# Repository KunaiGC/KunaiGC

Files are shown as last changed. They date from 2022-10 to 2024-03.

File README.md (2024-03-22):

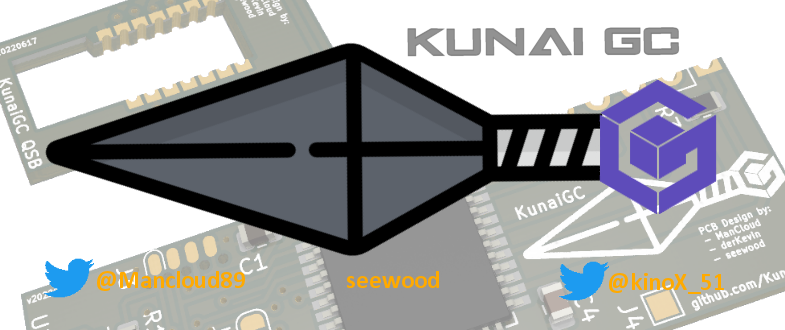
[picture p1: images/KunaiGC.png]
KunaiGC WIP


# KunaiGC
It is a OpenSource IPL modchip for the Nintendo Gamecube which provides a rich featureset. 
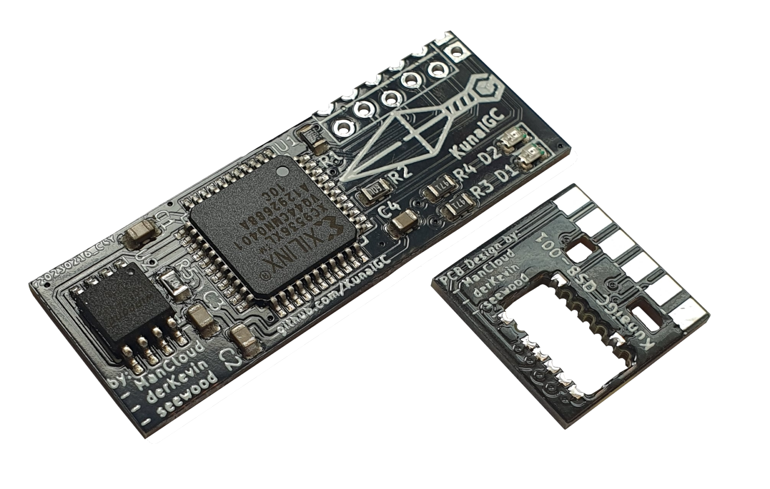
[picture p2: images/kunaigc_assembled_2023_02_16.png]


## Features
* QSB - Quick Solder Board for easy installation process
* Flash storage - boot directly into internal Swiss or GBI (Game Boy Interface)
* configurable boot-behavior
* Button mapped .dol file loading 
* Boot discs from all regions via build-in swiss
* KunaiUpdater - Update/Install Firmware, internal Swiss and GBI (Game Boy Interface) via SD-Card
* KunaiRecovery
* Cubeboot support

## Guides and Wiki

* just take a look at MachoNachos video:
[The Gamecube Just Got A NEW Modchip | The kunaiGC](https://www.youtube.com/watch?v=YmsjPn3J_iU)
* visit our [**Wiki-Page**](https://github.com/KunaiGC/KunaiGC/wiki) for detailed informations

## Installation

* The QSB is pretty straight forward and you only need to solder a few given spots. Make sure to check [**the solder guide**](https://github.com/KunaiGC/KunaiGC/wiki/Installation)

## Update the KunaiGC
* To update the KunaiGC firmware, the internal swiss version or install gbi (Game Boy Interface) please follow the [update instructions](https://github.com/KunaiGC/KunaiGC/wiki/Update-the-KunaiGC)

## You want to support our development?

head over to your favorite shop and order your own KunaiGC
* [Swiss] consoles4you: https://consoles4you.ch/en/kunaigc-mod-chip
* [US] stoneagegamer: https://stoneagegamer.com/kunaigc.html
* [France] mod in france: https://shop.modinfrance.fr/en/gamecube/60-kunaigc-for-gamecube.html
* [UK] retro upgrades: https://www.retroupgrades.co.uk/product/kunaigc-modchip/

## Credits
* #gc-forever crew: [Extrems](https://github.com/Extrems), [emu_kidid](https://github.com/emukidid) for doing the best job on swiss and homebrew, [novenary](https://github.com/9ary) especially for gaving us the permission to make his [gc-ipl](https://github.com/redolution/gc-ipl) great again 
* [tmbinc](https://github.com/tmbinc) - making ipl modchips possible
* happy_bunny and [webhdx](https://github.com/webhdx) for their research on the [shuriken attack](https://www.retro-system.com/shuriken_attack.htm) and [PicoBoot](https://github.com/webhdx/PicoBoot)
* KunaiGC beta testers from [CiBo](https://circuit-board.de/forum/), [psxtools.de](psxtools.de) and [EnterpriseFreak](https://github.com/EnterpriseFreak-v2)
* The handsome guys :p [Voultar](https://voultar.com/) and [MachoNacho](https://www.youtube.com/c/MachoNachoProductions)
* everyone who supports us 

## Licence 
 * The Hardware was developed under CC BY-NC-SA (Creative Commons Attribution-NonCommercial-ShareAlike 4.0 International)
 * The Software was developed under GNU GPL 2 (GNU GENERAL PUBLIC LICENSE 2)

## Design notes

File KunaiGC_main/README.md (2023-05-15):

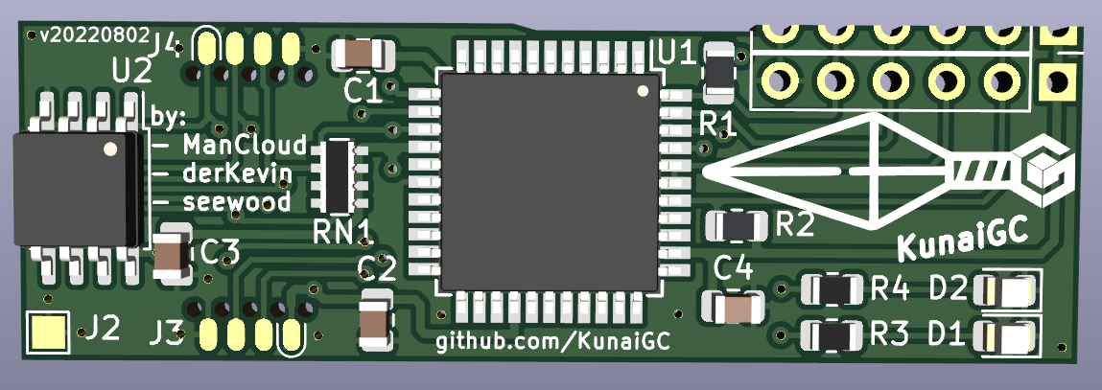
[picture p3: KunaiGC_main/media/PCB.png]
KunaiGC main PCB


# KunaiGC main PCB
The actual Modchip.

for its BOM please see [the Wiki](https://github.com/KunaiGC/KunaiGC/wiki/Build-the-KunaiGC)

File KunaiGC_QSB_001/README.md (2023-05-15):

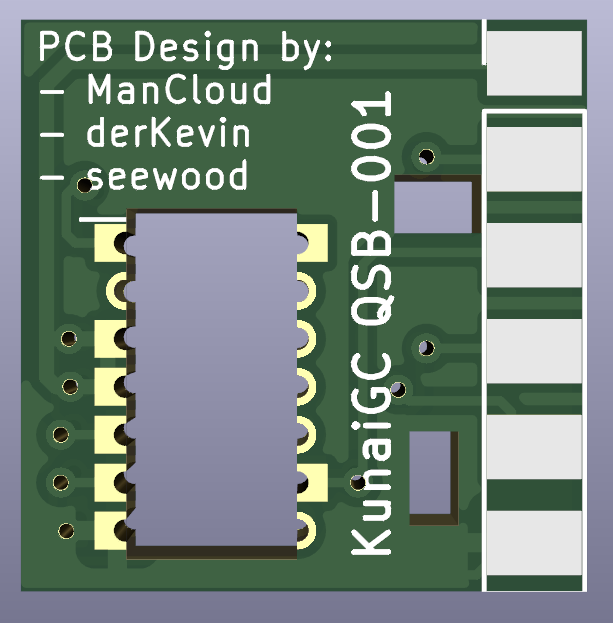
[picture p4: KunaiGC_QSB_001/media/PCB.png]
KunaiGC QSB_001 PCB


# KunaiGC QSB DOL-001
Quick-Solder-Board for DOL-001 Mainboard

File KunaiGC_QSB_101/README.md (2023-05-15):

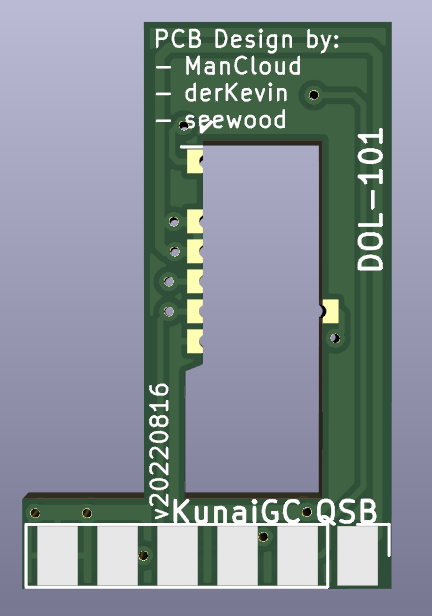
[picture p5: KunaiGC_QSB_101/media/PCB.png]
KunaiGC QSB_101 PCB


# KunaiGC QSB DOL-101
Quick-Solder-Board for DOL-101 Mainboard

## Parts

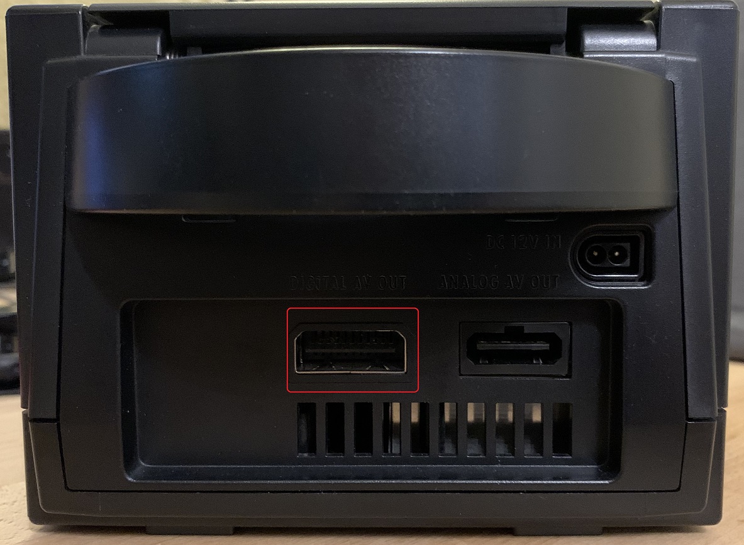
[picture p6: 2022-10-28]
images/where2start/gc_w_component.jpg

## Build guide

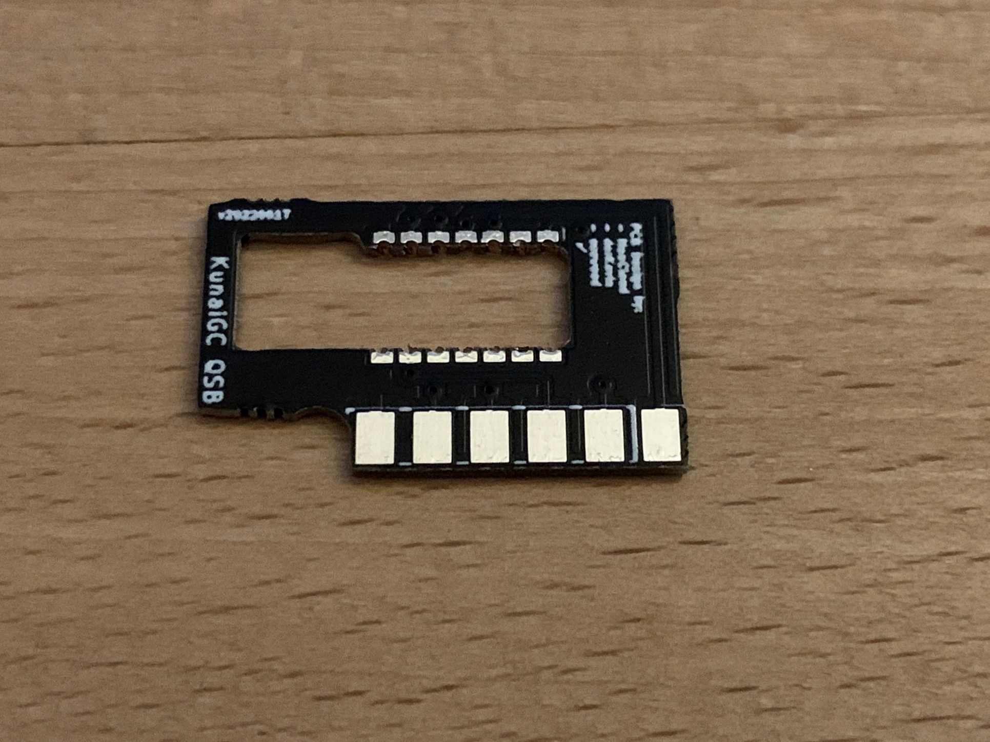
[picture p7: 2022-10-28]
images/solderkunai/betaunits/qsb.jpg

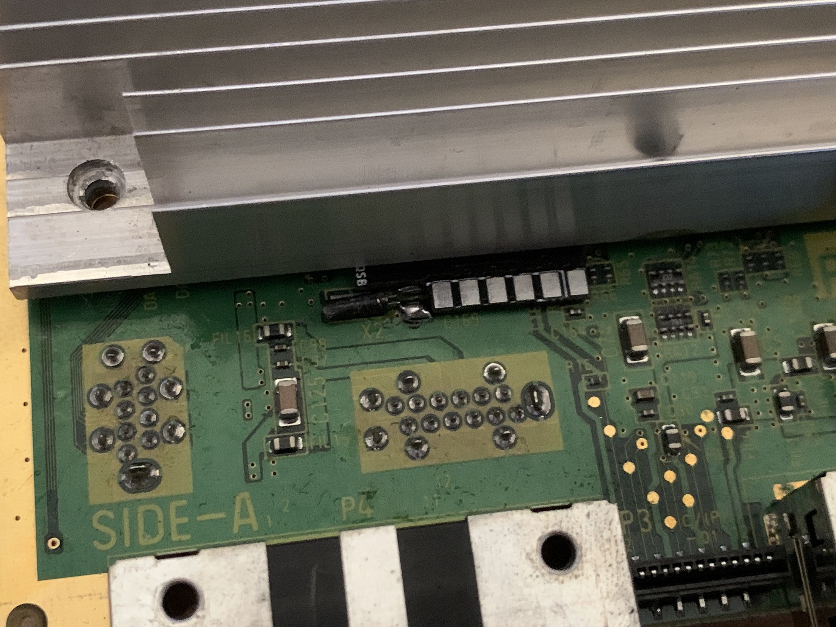
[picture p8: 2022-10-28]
images/solderkunai/betaunits/qsb_under_heatsink.jpg

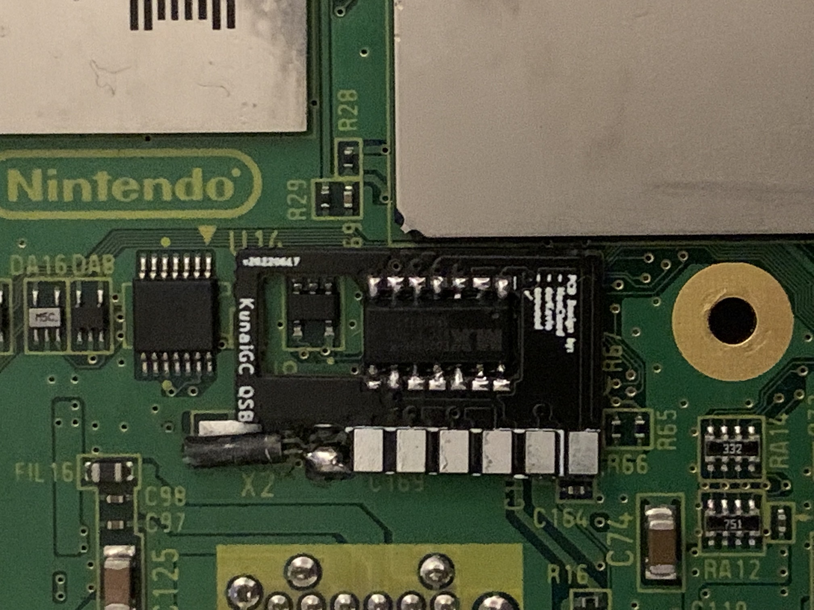
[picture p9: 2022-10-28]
images/solderkunai/betaunits/qsb_soldered.jpg

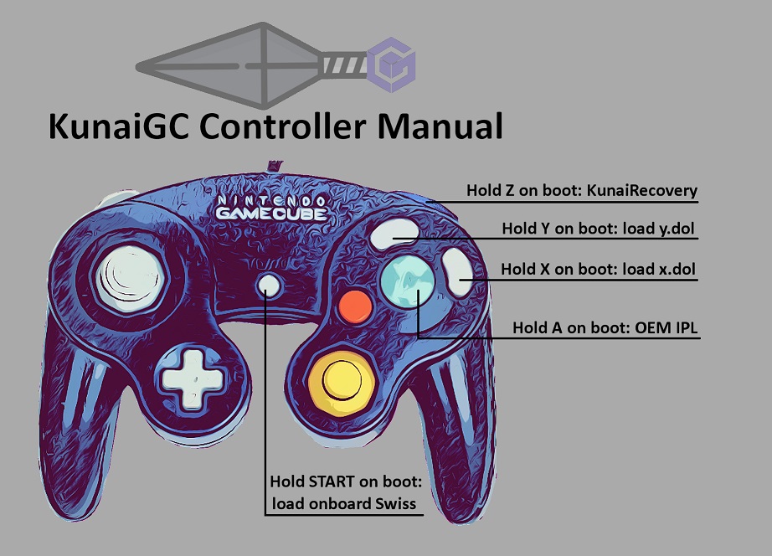
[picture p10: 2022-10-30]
images/Kunai_Controller_Manual.jpg

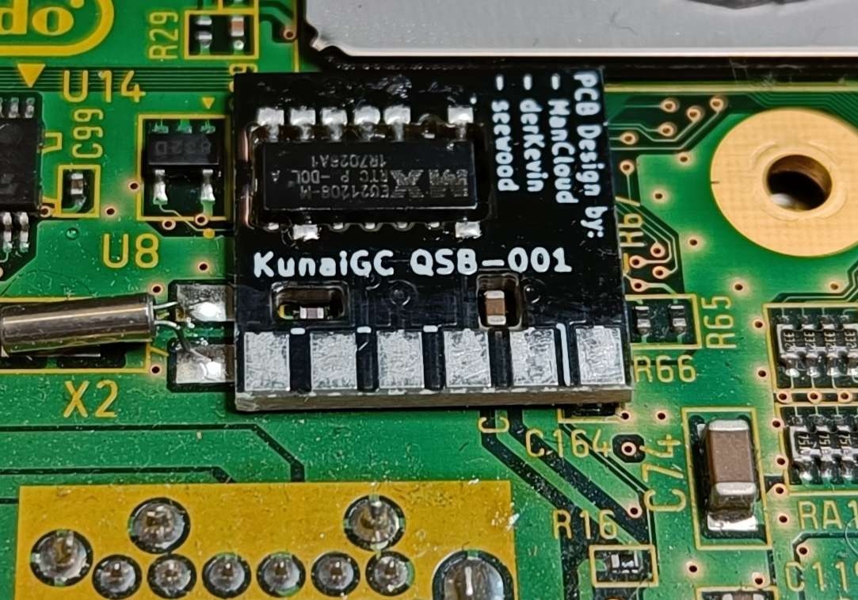
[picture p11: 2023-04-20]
images/solderkunai/soldered_qsb.jpg

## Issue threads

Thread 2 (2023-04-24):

PCB

Iceymidgit, 2023-04-24:
Can't find the file to download the PCB

Iceymidgit, 2023-05-18:
Would you be so kind to make Gerber files please

ManCloud, 2023-05-18:
I won't. I uploaded the Boardsfiles and kicad is free for use... Some suppliers even allow to directly upload the PCB file.
So please use what is there... It's much less effort for us! Thank you

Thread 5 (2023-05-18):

debugging install

Colrut, 2023-05-18:
good morning

I am trying to debug an install and had few questions

1 - please check this continuity map.  the colors are a bit hard to see so I numbered them.  point 2 does not seem to connect anyplace in the source picture.

2 - do all the points have to be soldered, or just the ones with soldering points.

3 - is there a guide for the flashing lights?  how do we use these do check an install?

thank you

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

Colrut, 2023-05-18:
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

better picture

ManCloud, 2023-05-18:
The pin 2 is on the picture below (in the wiki... Other side of the mainboard).

If everything is okay, both LEDs do something. If only one led is doing something most probably the exit.out line is defective.

If no led does anything, anything might be defective.

ManCloud, 2023-05-18:
EXI.CLK = your Nr. 7 ^^
It's pin #1 on the IPL chip.

Colrut, 2023-05-19:
Good morning

Thank you for your response and assistance.  Here are the steps that I have taken

1.	Checked/reflow all solder joints
2.	Checked continuity from chip to side of IPL, to IPL, and to the points on the KunaiGC itself
3.	Booted with and without the SD card with the special folder
4.	Held down d-pad down or start during boot

Each time light 1 will flash red and light 2 will then stay red.

It will always load regular gamecube menu – does not show the diagnostics or swiss

Any other suggestions?  Any chance of a bad or not programmed KunaiGC?

Thank you

Russell

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

Colrut, 2023-05-26:
[KunaiContinuity.pdf](https://github.com/KunaiGC/KunaiGC/files/11579085/KunaiContinuity.pdf)

I numbered the continuity to make it easier (at least for myself).  Feel free to share.
I likely had a bad board.  Tried direct wiring to the IPL with no benefit.
I installed a different QSB and Kunai in the same cube and it works...

However none of the expected buttons on controller (z, start, d-down) have any function - it always boots to regular gamecube menu.  I checked the controller port and controller.  But if I put a SD card in with the KUNAI folder it autoboots to Swiss from here.  This does not match with the expected behavior.

Any suggestions?

Colrut, 2023-05-28:
Is there a .DOL version of recovery that can be run to help troubleshoot?

indrora, 2023-06-06:
I'm having the same issue.

I got my KunaiGC from Consoles4you, verified all the connections, and the LEDs light as they should (momentary D1 -> solid D2).

No button presses activate anything: Holding start or Z simply boots straight to the normal Gamecube IPL.

ManCloud, 2023-06-06:
I was about to write that 3rd party controller stuff ^^

The embedded recovery unfortunately should not be touched... But can...
This would take the risk of bricking the KunaiGC.

So for recovery stuff it seems there always needs to be an OEM controller connected.

But for the normal operation it should definitely be possible to do so.

I have no 3rd party controllers here but could test with blueretro 👌

indrora, 2023-06-06:
I would absolutely suggest testing against these specific third party controllers:

* the ones from [CirKa](https://www.amazon.com/CirKa-Wired-Controller-GameCube-Wii-Purple/dp/B000UQCER6), which are very popular in shops here and which are likely based on the most common of clone designs
* BlueRetro (either external or the Laser Bear Industries internal mod)
* the Retro Fighters [wireless gamecube controller](https://retrofighters.com/our-collection/battlergc-next-gen-wireless-gamecube-controller/)
* a PhobGCC

BlueRetro and PhobGCC being open source makes things easier -- the current PhobGCC is built around an RP2040 and the BlueRetro is around an esp32. If PhobGCC and BlueRetro can't activate the debug or built-in recovery, that's a bad problem.

ManCloud, 2023-06-15:
In my opinion there is no way to implement support for wireless controllers.
It would make the overall booting process very slow as we can never be sure a wireless controller is connected during boot especially when it comes to bluetooth controllers.

The internal Laser-Bear BlueRetro board on the other hand should already work as it usually is powered before the console itself is.

i'll see what i can do regarding the other controllers 👍

TharathielCB, 2023-11-23:
@Colrut: I added your suggestion to the wiki. https://github.com/KunaiGC/KunaiGC/wiki/Installation#testing

@indrora: We will look over the 3rd party Controller topic once we have some of them for testing here, but right now this is not the highest priority. Please open a separate issue if this topic is still present.

Closed 2023-11-23.

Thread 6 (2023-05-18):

Pcb holes

iceyman, 2023-05-18:
Pcb way sent me this

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

ManCloud, 2023-05-27:
This must be new because we ordered from jlcpcb and PCBway and never got this issue.

Unfortunately I can't just change the file and upload without testing because I couldn't guarantee it'll work as this layout does.

iceyman, 2023-07-19:
Have u added this branch?? As I tried again same issue

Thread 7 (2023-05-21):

Resistor values

7407chrisl, 2023-05-21:
Hi, I was little confused on the recommended resistor values.  In the PCB schematic it says R1 is 100ohm and R3 and R4 is 470ohm.  In the wiki section it says to use 220ohm for all three.  Then the boards being sold by consoles4you are using 22ohm for R1 and 220ohm for R3 and R4.  Thanks!

ManCloud, 2023-05-27:
Yeah it's a little inconsistent as it really doesn't matter that much.
We'll fix that and enter same values everywhere.

All combinations work just fine as Re and R4 are current limiting resistors for the LEDs and R1 ist just a safety resistor that could even be shorted.

TharathielCB, 2023-11-23:
wiki updated

Closed 2023-11-23.

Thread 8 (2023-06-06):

Question - Able to boot into Swiss by default, IE reverse the start button on boot

0mni, 2023-06-06:
See subject, want to be able to boot into Swiss on powering on the gamecube by default. Didn't see an option that jumped out to me that would do that, does one exists and if not, can it be added in future?

ManCloud, 2023-06-08:
Will be added in the future 👌

0mni, 2023-06-08:
> Will be added in the future 👌

Awesome!

Closed 2023-06-08.

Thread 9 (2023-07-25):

No video output

raguila3, 2023-07-25:
I’ve installed the KunaiGC chip, had run a game through Swiss and everything. I was playing with the settings but changing them back and then suddenly I don’t have video output anymore. I got scared that I might have shorted my KunaiGC chip as I did not cover the pins in the back. I opened my GC and I noticed that the KunaiGC chip doesn’t blink the LED lights like it did at the initial boot. I desoldered it to check the pins in the back and attached is a picture of them. If the pins look fine, is it normal for the board to not blink the LED lights anymore? I want to make sure my problem is not the chip and hopefully just my HDMI converter not being strong enough.

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

TharathielCB, 2023-11-23:
Hi,

if you need support with the installation please join the new retro discord. https://discord.gg/TYRYdXsBxr
To get access to the Nintendo section you need to select the designated role.

Closed 2023-11-23.

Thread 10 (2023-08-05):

PCB thickness

7407chrisl, 2023-08-05:
Hi,

What PCB thickness do you recommend when ordering the QSB and main board?

Thanks

TharathielCB, 2023-11-23:
QSB: 1,2 mm
KunaiGC: 0,8 mm

TharathielCB, 2023-11-23:
added in wiki:
https://github.com/KunaiGC/KunaiGC/wiki/Build-the-KunaiGC#recommend-pcb-thickness

Closed 2023-11-23.

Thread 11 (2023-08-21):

Kunai Inactive

BodenSun, 2023-08-21:
Hi, I installed my KunaiGC chip and got full continuity and even the proper lights to make sure it was working (flash on 1 then light on 2). Then when I tested the console I found that none of the button combos were doing anything. Start didn't boot swiss, z didn't boot KunaiRecovery, D-Pad Down didn't enter debugging mode, I got nothing. I used an OEM controller and tested using the LazerBear internal BlueRetro controller ports and the original/stock ports. It's almost like it isn't installed at all.

Closed 2023-08-21.

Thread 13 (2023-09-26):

Different BOM

gnaghi, 2023-09-26:
On the wiki page (https://github.com/KunaiGC/KunaiGC/wiki/Build-the-KunaiGC), 2 types of resistor are needed : 1 x 10k ohm, and 3 x 220 ohm, but, on the schematic, there are 1x 10k ohm, 1 x 100 ohm, and 2 x 470 ohm.

I guess the good values are the one on the schematic ?

TharathielCB, 2023-11-23:
wiki updated

Closed 2023-11-23.

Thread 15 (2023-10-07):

start.dol file doesn't override onboard swiss

axmccx, 2023-10-07:
I've placed the latest version of Swiss on my SD2SP2, on the root of the SD card named `start.dol`, however when I hold start at bootup, it still boots the older onboard version of Swiss. Anything I should be doing differently?

Alternatively, is there any way to update the on board Swiss? It kinda defeat the benefit of this mod if it can't be updated.

TharathielCB, 2023-11-23:
To update the internal swiss please follow the [KunaiUpdater guide](https://github.com/KunaiGC/KunaiGC/wiki/Update-the-KunaiGC)
You will found the dol in the release

Closed 2023-11-23.

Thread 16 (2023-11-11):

What is the pinouts for the kunaigc to ipl chip???

zin0099, 2023-11-11:
I have lost my qsb and decided to wire the kunai to the ipl with 30.  Gauge wire...but that 7th pad that isn't marked on the test page with no color isn't marked....where do the wires go...no diagram and the only 3 videos of the install don't talk about it

ManCloud, 2023-11-23:
There is a mapping in the Installation section in the wiki
https://github.com/KunaiGC/KunaiGC/wiki/Installation
the pad you're most likely referring to (can only guess without a picture) is only for stability reasons and not connected to the KunaiGC at all 👍

Closed 2023-11-23.

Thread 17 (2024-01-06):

Clarity of wiki instructions for programming the CPLD and flash

Rhombic-Drive, 2024-01-06:
Hi,

I've currently built a few KunaiGCs and am ready to perform the flashing steps. The CPLD seems straghtforward, although I am not sure which jedec file I should be using to flash, as that is not mentioned in the wiki. The only IPL .jed file that I could find for the xc9536 was one bundled with the Shuriken Attack. Will this do the job for providing a basic IPL or should I be using something else?

I guess the wiki page on programming the flash memory is incomplete--I noticed the labels on the Raspberry Pi GPIO pins don't correspond to the SPI SOICbite pinouts exactly. Some clarification here would be helpful. I think the appropriate .bin file for the
16Mx8 flash IC is KunaiGC_lfs_16M.bin.

Thank you

ManCloud, 2024-01-06:
First of all: the CPLD related stuff is in the KubaiGC-IPL Repository.
Second: what do you mean with "a few"...
Sounds like you're not building for personal use which would violate the licenses (non commercial use permitted)...
Hope that's not, what it means...

Rhombic-Drive, 2024-01-06:
I made 3. One is for myself, the other 2 are gifts. I'm not selling them.

I've seen the IPL repository; I didn't see a jed file but now that I look at the makefile I can see that it's generated there. Thanks. That would be good info to include in the wiki as well.

ManCloud, 2024-01-07:
Allright just wanted to make sure ^^
Unfortunately it happens way too often that people can't read license properly 🙈

We'll add that to the wiki, thanks for your input 👍

For the SPI part: i can see your confusion. This is because people tend to name the lines differently: some just call it DO (for data out) others call is MOSI (for Master Out Slave In). IIRC the picture of the RPI is referenced to the nomenclature used on "https://wiki.flashrom.org/RaspberryPi" as the schematics (and layout) uses the SPI nomenclature.

Usually this should not be a "big deal" for people dealing with this on a regular basis but can be quite confusing for people who don't.

we'll add a connection table in the near future 👍

Rhombic-Drive, 2024-01-07:
Thanks, that's helpful. I have programmed the CPLD successfully. I ended up using WSL to run the Linux version of ISE 14.7, since the Windows version was a headache. If you're using Ubuntu you need to add the universal repository to get a libncurses5 package. I tried openSUSE first, but the WSL X11 support wasn't working. Now I'm working on programming the flash but have a few questions:

1. Do the JTAG SOICbite connections still need to be maintained on the GPIO pins when connecting the SPI pins? I guess this is the case from what I've read on how SPI flash is programmed with these CPLDs.
2. For programming the SPI flash, the xc3sprog documentation mentions needing a bitfile (which isn't included by default in their `bscan_spi` folder. Do I need to use the Xilinx tools (Impact) approach here? In this case I'd have to figure that out first.

ManCloud, 2024-01-08:
The SPI-Flash needs to be programmed on beforehand (at least that is what I always did as in circuit programming did not work once the cpld was placed.

Therefore I used a tl866ii programmer or friends of mine used a raspberry pi for it.

If there is actually a way to upload it via jtag: I don't know.

And for cpld programming I used the Windows ISE (with virtual box first, then with fixes by gamebox systems) on win11.

Programmed cia impact.

Iirc it's the only way capable of erasing locked cpld therefore I myself never investigated in openocd stuff etc.

Rhombic-Drive, 2024-01-08:
From what I've seen the support isn't there in xc3sprog to make it easy when using the XC9536XL. I think going that route, or the ISE tools approach, is beyond my current skill level, so I will try using flashrom on my Pi first, since this W25 flash is supported. I will report back if this works, maybe that will be the easiest way for people who are already using their Pi for the CPLD.

Rhombic-Drive, 2024-01-16:
Unfortunately it's not, at least from what I can see. I desoldered the flash and will program it once my SOIC clip comes in. I'll report back after that. I can also write up my process for doing it if that would be helpful.

Rhombic-Drive, 2024-02-29:
Well, it took a while for me to get some decent QSB boards (needed to use PCBWay and re-order them--the JLCPCB ones were routed out way off target). I did end up programming the flash using flashrom on my Pi 3b. It appeared to have programmed successfully.

Unfortunately things aren't working from what I can tell. The solder joints are all good, and no neighboring pins on the QSB board are shorted. D1 lights up when the system is turned on. I am not currently getting any video signal out. I'm going to do some troubleshooting and make sure with a scope that I'm not getting the right signals out, in case there is just a problem with my OSSC getting sync or something.

I'll try to contribute to the wiki with my approach if I can get everything working.

olDirdey, 2024-05-24:
> Edit: After I removed the Kunai main board (QSB still there) it's working. So something may have gone wrong during programming, or it got ESD'd or something. I'll do some more troubleshooting.

which cpld did you install? if you take the source files and do not change anything, you will generate a firmware for the 9572. if you use the 9536 you have to change this before compiling.

Rhombic-Drive, 2024-05-24:
> > Edit: After I removed the Kunai main board (QSB still there) it's working. So something may have gone wrong during programming, or it got ESD'd or something. I'll do some more troubleshooting.
>
> which cpld did you install? if you take the source files and do not change anything, you will generate a firmware for the 9572. if you use the 9536 you have to change this before compiling.

I found this explanation in the Discord; I did change the firmware source file to 9536 and it worked after that. All's well.

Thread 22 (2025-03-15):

Cannot update files

64801965, 2025-03-15:
I place the swiss.dol and kunailoader.dol into the KUNAIGC folder o the root of the SD card, then access the kunaimenu, but I can't see files displayed under the update files option, so I can't update the internal flash.

64801965, 2025-03-15:
picture as follow:
[https://i.postimg.cc/xTBLLN4H/IMG-20250315-100551.jpg](url)

64801965, 2025-03-29:
It's solved, after changing input port from slot B to slot A, files to be update have displayed under the update files option. It is the hardware problem on my console.

TharathielCB, 2025-07-14:
Solved

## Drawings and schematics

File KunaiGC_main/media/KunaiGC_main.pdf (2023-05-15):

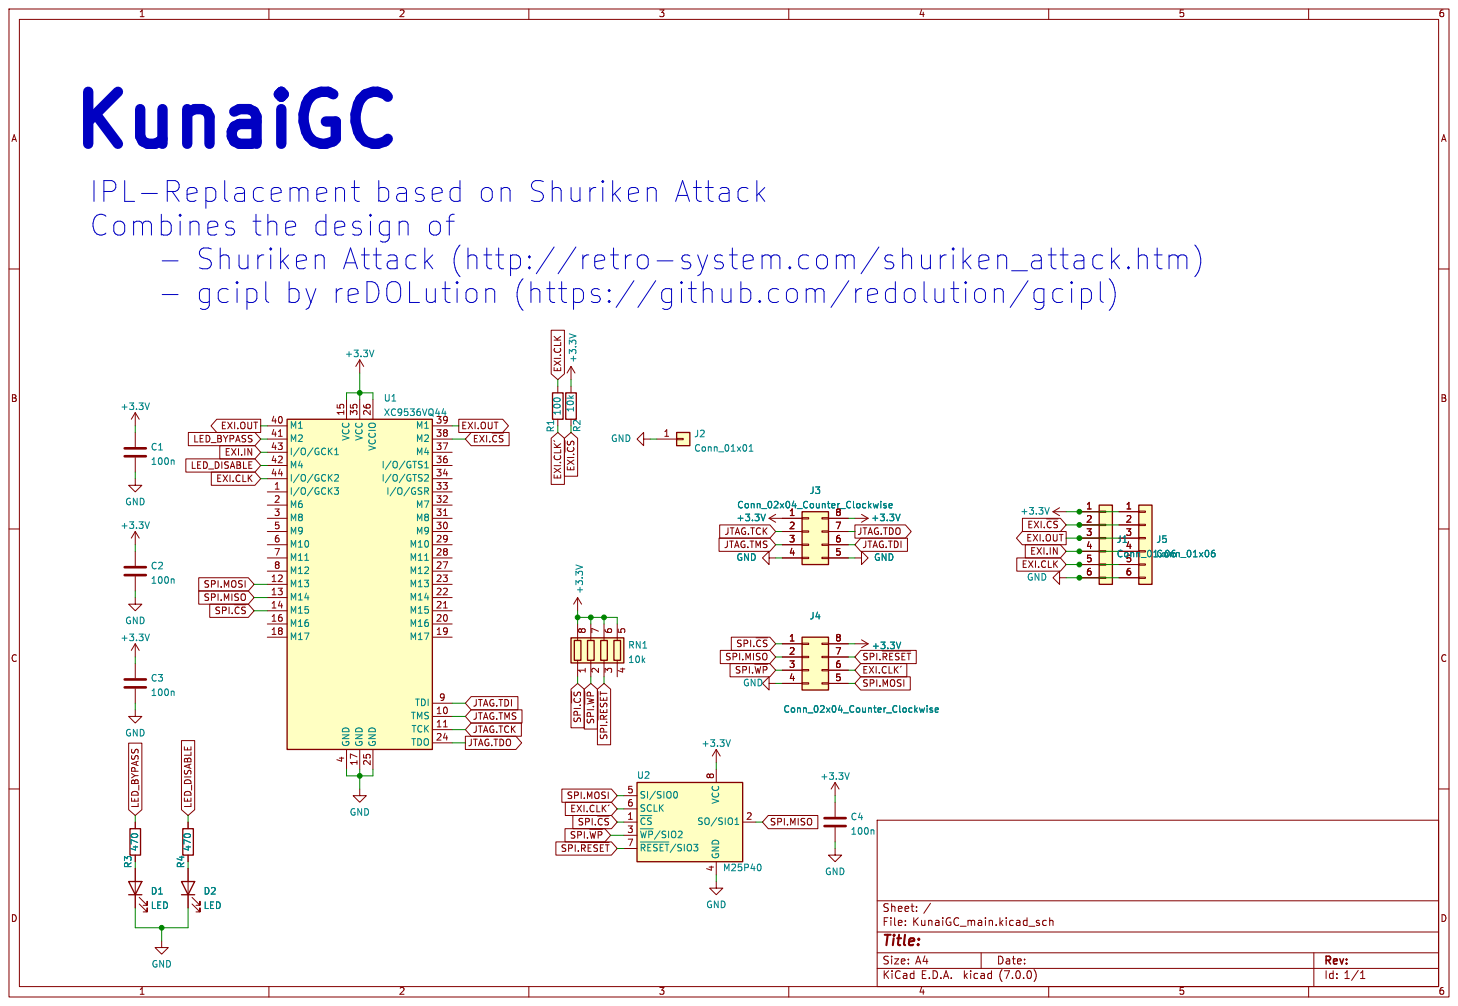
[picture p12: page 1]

- gcipl by reDOLution (https://github.com/redolution/gcipl)

EXI.~{CS} EXI.OUT EXI.CLK

SPI.~{WP} SPI.MISO
þÿEXI.CLK´ SPI.MOSI SPI.~{CS}SPI.~{RESET} SPI.~{CS} SPI.~{WP}

EXI.~{CS} EXI.IN

SPI.~{CS} SPI.MISO

Id: 1/1 Title: File: KunaiGC_main.kicad_sch Sheet: /

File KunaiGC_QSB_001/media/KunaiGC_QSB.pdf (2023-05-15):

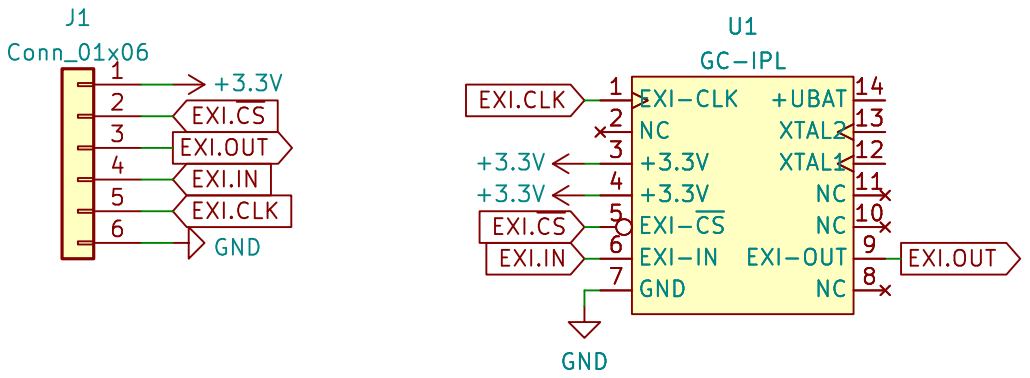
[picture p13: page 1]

Id: 1/1 Title: File: KunaiGC_QSB.kicad_sch Sheet: /

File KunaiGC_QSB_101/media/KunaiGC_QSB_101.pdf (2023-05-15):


Id: 1/1 Title: File: KunaiGC_QSB_101.kicad_sch Sheet: /

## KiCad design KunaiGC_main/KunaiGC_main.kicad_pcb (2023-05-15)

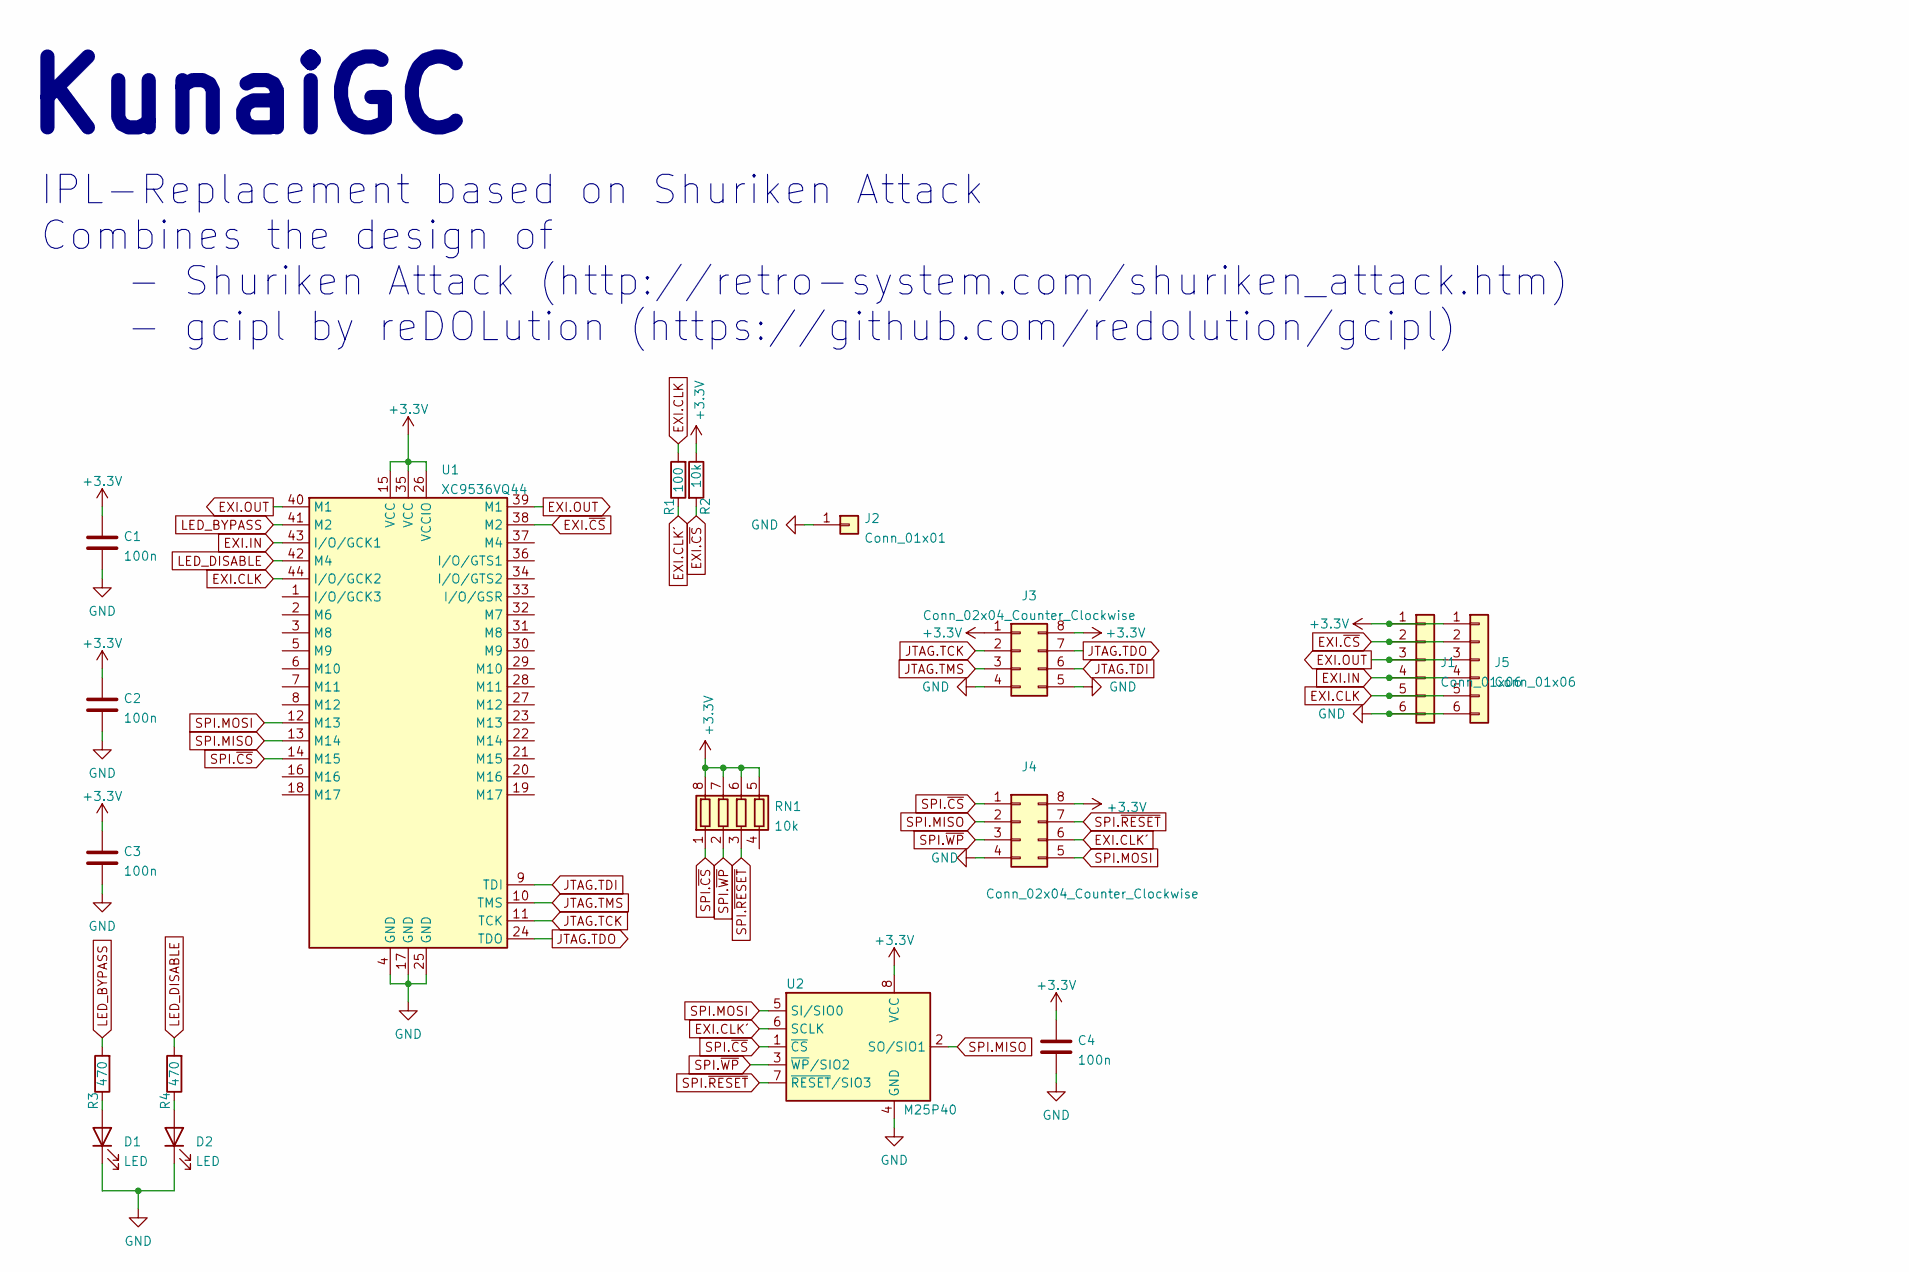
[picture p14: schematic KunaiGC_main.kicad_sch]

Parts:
C1, C2, C3, C4: 100n; C_0805_2012Metric
D1, D2: LED; LED_0805_2012Metric
J1, J5: Conn_01x06; PinHeader_1x06_P2.54mm_Vertical
J2: Conn_01x01; TestPoint_Pad_1.5x1.5mm
J3, J4: Conn_02x04_Counter_Clockwise; SOIC_clipProgSmall
R1: 100; R_0805_2012Metric
R2: 10k; R_0805_2012Metric
R3, R4: 470; R_0805_2012Metric
RN1: 10k; R_Array_Concave_4x0603
U1: XC9536VQ44; TQFP-44_10x10mm_P0.8mm
U2: M25P40; SOP-8-Wide

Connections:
+3V3: C1.1, C2.1, C3.1, C4.1, J1.1, J3.1, J3.8, J4.8, J5.1, R2.1, RN1.5 (R4.2), RN1.6 (R3.2), RN1.7 (R2.2), RN1.8 (R1.2), U1.15 (VCC), U1.26 (VCCIO), U1.35 (VCC), U2.8 (VCC)
EXI.CLK: J1.5, J5.5, R1.2, U1.44 (I/O/GCK2)
EXI.CLK´: J4.6, R1.1, U2.6 (SCLK)
EXI.IN: J1.4, J5.4, U1.43 (I/O/GCK1)
EXI.OUT: J1.3, J5.3, U1.39 (M1), U1.40 (M1)
EXI.~CS: J1.2, J5.2, R2.2, U1.38 (M2)
GND: C1.2, C2.2, C3.2, C4.2, D1.1 (K), D2.1 (K), J1.6, J2.1, J3.4, J3.5, J4.4, J5.6, U1.4 (GND), U1.17 (GND), U1.25 (GND), U2.4 (GND)
JTAG.TCK: J3.2, U1.11 (TCK)
JTAG.TDI: J3.6, U1.9 (TDI)
JTAG.TDO: J3.7, U1.24 (TDO)
JTAG.TMS: J3.3, U1.10 (TMS)
LED_BYPASS: R3.2, U1.41 (M2)
LED_DISABLE: R4.2, U1.42 (M4)
unnamed: D1.2 (A), R3.1
unnamed: D2.2 (A), R4.1
SPI.MISO: J4.2, U1.13 (M14), U2.2 (SO/SIO1)
SPI.MOSI: J4.5, U1.12 (M13), U2.5 (SI/SIO0)
SPI.~CS: J4.1, RN1.1 (R1.1), U1.14 (M15), U2.1 (~CS)
SPI.~RESET: J4.7, RN1.3 (R3.1), U2.7 (~RESET/SIO3)
SPI.~WP: J4.3, RN1.2 (R2.1), U2.3 (~WP/SIO2)

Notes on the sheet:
IPL-Replacement based on Shuriken Attack Combines the design of - Shuriken Attack (http://retro-system.com/shuriken_attack.htm) - gcipl by reDOLution (https://github.com/redolution/gcipl)
KunaiGC

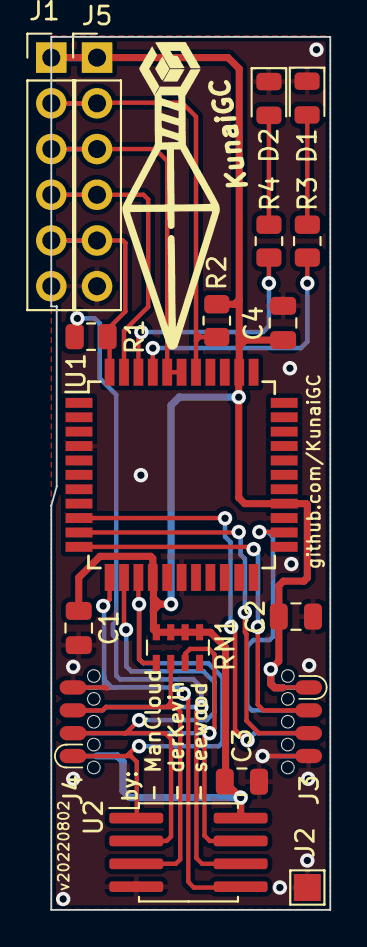
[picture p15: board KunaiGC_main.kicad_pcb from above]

Board: 2 copper layers, 15.5 x 48.5 mm, 18 parts (0 on the bottom side), 20 nets.

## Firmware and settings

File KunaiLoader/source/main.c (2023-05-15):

#include <stdio.h>
#include <stdlib.h>
#include <sdcard/gcsd.h>
#include <string.h>
#include <malloc.h>
#include <unistd.h>
#include <ogc/lwp_watchdog.h>
#include <fcntl.h>
#include <ogc/system.h>
#include "etc/ffshim.h"
#include "fatfs/ff.h"

#include "etc/stub.h"
#define STUB_ADDR  0x80001000
#define STUB_STACK 0x80003000

int screenheight;
int vmode_60hz = 0;
u32 retraceCount;

#include "gfx/kunai_logo.h"
#include "gfx/gfx.h"
#include "spiflash/spiflash.h"
#include "kunaigc/kunaigc.h"
#define KUNAI_VERSION "1.0"

u8 *dol = NULL;
char *path = "/KUNAIGC/ipl.dol";

extern lfs_t lfs;
extern lfs_file_t lfs_file;
extern struct lfs_config cfg;

struct shortcut {
  u16 pad_buttons;
  char *path;
} shortcuts[] = {
  {PAD_BUTTON_A,     "/a.dol"    },
  {PAD_BUTTON_B,     "/b.dol"    },
  {PAD_BUTTON_X,     "/x.dol"    },
  {PAD_BUTTON_Y,     "/y.dol"    },
  {PAD_BUTTON_LEFT,  "/left.dol" },
  {PAD_BUTTON_RIGHT, "/right.dol"},
  {PAD_BUTTON_UP,    "/up.dol"   },
  // Down is reserved for debuging (delaying exit).
  // NOTE: Shouldn't use L, R or Joysticks as analog inputs are calibrated on boot.
};
int num_shortcuts = sizeof(shortcuts)/sizeof(shortcuts[0]);

void dol_alloc(int size)
{
    int mram_size = (SYS_GetArenaHi() - SYS_GetArenaLo());
    kprintf("Memory available: %iB\n", mram_size);

    kprintf("DOL size is %iB\n", size);

    if (size <= 0)
    {
        kprintf("Empty DOL\n");
        return;
    }

    dol = (u8 *) memalign(32, size);

    if (!dol)
    {
        kprintf("Couldn't allocate memory\n");
    }
}

int load_fat(const char *slot_name, const DISC_INTERFACE *iface_)
{
    int res = 1;

    kprintf("Trying %s\n", slot_name);

    FATFS fs;
    iface = iface_;
    if (f_mount(&fs, "", 1) != FR_OK)
    {
        kprintf("Couldn't mount %s\n", slot_name);
        res = 0;
        goto end;
    }

    char name[256];
    f_getlabel(slot_name, name, NULL);
    kprintf("Mounted %s as %s\n", name, slot_name);

    kprintf("Reading %s\n", path);
    FIL file;
    if (f_open(&file, path, FA_READ) != FR_OK)
    {
        kprintf("Failed to open file\n");
        res = 0;
        goto unmount;
    }

    size_t size = f_size(&file);
    dol_alloc(size);
    if (!dol)
    {
        res = 0;
        goto unmount;
    }
    UINT _;
    f_read(&file, dol, size, &_);
    f_close(&file);

unmount:
    kprintf("Unmounting %s\n", slot_name);
    iface->shutdown();
    iface = NULL;

end:
    return res;
}

unsigned int convert_int(unsigned int in)
{
    unsigned int out;
    char *p_in = (char *) &in;
    char *p_out = (char *) &out;
    p_out[0] = p_in[3];
    p_out[1] = p_in[2];
    p_out[2] = p_in[1];
    p_out[3] = p_in[0];
    return out;
}

#define PC_READY 0x80
#define PC_OK    0x81
#define GC_READY 0x88
#define GC_OK    0x89

int load_usb(char slot)
{
    kprintf("Trying USB Gecko in slot %c\n", slot);

    int channel, res = 1;

    switch (slot)
    {
    case 'B':
        channel = 1;
        break;

    case 'A':
    default:
        channel = 0;
        break;
    }

    if (!usb_isgeckoalive(channel))
    {
        kprintf("Not present\n");
        res = 0;
        goto end;
    }

    usb_flush(channel);

    char data;

    kprintf("Sending ready\n");
    data = GC_READY;
    usb_sendbuffer_safe(channel, &data, 1);

    kprintf("Waiting for ack...\n");
    while ((data != PC_READY) && (data != PC_OK))
        usb_recvbuffer_safe(channel, &data, 1);

    if(data == PC_READY)
    {
        kprintf("Respond with OK\n");
        // Sometimes the PC can fail to receive the byte, this helps
        usleep(100000);
        data = GC_OK;
        usb_sendbuffer_safe(channel, &data, 1);
    }

    kprintf("Getting DOL size\n");
    int size;
    usb_recvbuffer_safe(channel, &size, 4);
    size = convert_int(size);

    dol_alloc(size);
    unsigned char* pointer = dol;

    if(!dol)
    {
        res = 0;
        goto end;
    }

    kprintf("Receiving file...\n");
    while (size > 0xF7D8)
    {
        usb_recvbuffer_safe(channel, (void *) pointer, 0xF7D8);
        size -= 0xF7D8;
        pointer += 0xF7D8;
    }
    if(size)
        usb_recvbuffer_safe(channel, (void *) pointer, size);

end:
    return res;
}

extern u8 __xfb[];

#define MIN_INDEX 0
#define MAX_INDEX 3
void draw_menu(void){
	u32 jedec_id = kunai_get_jedecID();
	cfg.block_count = (((1 << (jedec_id & 0xFFUL)) - KUNAI_OFFS) / cfg.block_size);

	int err = lfs_mount(&lfs, &cfg);

	// reformat if we can't mount the filesystem
	// this should only happen on the first boot
	if (err) {
		lfs_format(&lfs, &cfg);
		lfs_mount(&lfs, &cfg);
	}
	// read current count
	uint32_t boot_count = 0;
	lfs_file_open(&lfs, &lfs_file, "boot_count", LFS_O_RDWR | LFS_O_CREAT);
	lfs_file_read(&lfs, &lfs_file, &boot_count, sizeof(boot_count));

    // update boot count
    boot_count += 1;
    lfs_file_rewind(&lfs, &lfs_file);
    lfs_file_write(&lfs, &lfs_file, &boot_count, sizeof(boot_count));

    // remember the storage is not updated until the file is closed successfully
    lfs_file_close(&lfs, &lfs_file);

    // release any resources we were using
    lfs_unmount(&lfs);

	int8_t cursor_idx = 0;
		ClearScreen();

		writeLine(0, 0, 640, 480, COL_HIGHLIGHT);
		drawCircle(320, 240, 50, COL_HIGHLIGHT);

		int x = 50;
		for(uint8_t i = 0; i < 10; i++) {

			drawBitmap(640-250-25*i, i*x , image_data_KunaiGCLogo, 250, 81, 0);
		}

		drawString(50, 300,(unsigned char *) "KunaiGC Rockz!", getColor(255,255,255), getColor(255,255,255), 4,4);

	while(1){
		ShowScreen();

		CON_InitEx(rmode, 20, 20, 240, 240);


		kprintf("KunaiGC v%s\n", KUNAI_VERSION);
		kprintf("\tBy\t ManCloud\n"
				"\t\t seewood\n"
				"\t\t derKevin\n\n");
		kprintf("SPIFlash-JEDEC ID: 0x%06X\n", kunai_get_jedecID());

		kprintf("\n%s Deactivate KunaiGC", cursor_idx == 0 ? "*" : "");
		kprintf("\n%s Reactivate KunaiGC", cursor_idx == 1 ? "*" : "");
		kprintf("\n%s Enable Passthrough", cursor_idx == 2 ? "*" : "");
		kprintf("\n%s Disable Passthrough", cursor_idx == 3 ? "*" : "");

		kprintf("\n\nPress 'B' to return.");

		kprintf("\n\nKunaiGC Menu Boot Count: %u", boot_count);

		PAD_ScanPads();
		u16 currBtns = PAD_ButtonsHeld(0);

		while(currBtns == PAD_ButtonsHeld(0)) {
			PAD_ScanPads();
			VIDEO_WaitVSync();
		}

		if(PAD_ButtonsHeld(0) & PAD_BUTTON_A) {
			while(PAD_ButtonsHeld(0) & PAD_BUTTON_A) PAD_ScanPads();
			switch (cursor_idx) {
			case 0: kunai_disable(); break;
			case 1: kunai_reenable(); break;
			case 2: kunai_enable_passthrough(); break;
			case 3: kunai_disable_passthrough(); break;
			default: break;
			}
		}

		if (PAD_ButtonsHeld(0) & PAD_BUTTON_DOWN){
			while(PAD_ButtonsHeld(0) & PAD_BUTTON_DOWN) PAD_ScanPads();
			cursor_idx++;
			cursor_idx = MIN(cursor_idx, MAX_INDEX);
		}

		if (PAD_ButtonsHeld(0) & PAD_BUTTON_UP){
			while(PAD_ButtonsHeld(0) & PAD_BUTTON_UP) PAD_ScanPads();
			cursor_idx--;
			cursor_idx = MAX(cursor_idx, MIN_INDEX);
		}

		if (PAD_ButtonsHeld(0) & PAD_BUTTON_B){
			while(PAD_ButtonsHeld(0) & PAD_BUTTON_UP) PAD_ScanPads();
			ClearScreen();
			break;
		}


	}
}

int load_lfs(const char * filePath)
{
    int res = 1;

    kprintf("Trying lfs\n");

    //update block_count regarding to flash chip
    u32 jedec_id = kunai_get_jedecID();
    cfg.block_count = (((1 << (jedec_id & 0xFFUL)) - KUNAI_OFFS) / cfg.block_size);

	int err = lfs_mount(&lfs, &cfg);

    if (err != LFS_ERR_OK)
    {
        kprintf("Couldn't mount lfs\n");
        res = 0;
        goto end;
    }

    kprintf("lfs mounted\n");

    kprintf("Reading %s\n", filePath);
    if (lfs_file_open(&lfs, &lfs_file, filePath, LFS_O_RDWR) != LFS_ERR_OK)
    {
        kprintf("Failed to open file\n");
        res = 0;
        goto unmount;
    }

    size_t size = lfs_file_size(&lfs, &lfs_file);
    dol_alloc(size);
    if (!dol)
    {
        res = 0;
        goto unmount;
    }
    lfs_file_read(&lfs, &lfs_file, dol, size);
    lfs_file_close(&lfs, &lfs_file);
unmount:
    kprintf("Unmounting lfs\n");
    lfs_unmount(&lfs);
end:
    return res;
}

GXRModeObj *rmode = NULL;

int main()
{
main_start:
	VIDEO_Init ();		/*** ALWAYS CALL FIRST IN ANY LIBOGC PROJECT!
					     Not only does it initialise the video
					     subsystem, but also sets up the ogc os
	 ***/

	PAD_Init ();			/*** Initialise pads for input ***/

	// get default video mode
	rmode = VIDEO_GetPreferredMode(NULL);

	switch (rmode->viTVMode >> 2)
	{
	case VI_PAL:
		// 576 lines (PAL 50Hz)
		// display should be centered vertically (borders)
		//Make all video modes the same size so menus doesn't screw up
		rmode = &TVPal576IntDfScale;
		rmode->xfbHeight = 480;
		rmode->viYOrigin = (VI_MAX_HEIGHT_PAL - 480)/2;
		rmode->viHeight = 480;


		vmode_60hz = 0;
		break;

	case VI_NTSC:
		// 480 lines (NTSC 60hz)
		vmode_60hz = 1;
		break;

	default:
		// 480 lines (PAL 60Hz)
		vmode_60hz = 1;
		break;
	}

	/* we have component cables, but the preferred mode is interlaced
	 * why don't we switch into progressive?
	 * (user may not have progressive compatible display but component input)*/
	if(VIDEO_HaveComponentCable()) rmode = &TVNtsc480Prog;
	// configure VI
	VIDEO_Configure (rmode);

	/*** Clear framebuffer to black ***/
	VIDEO_ClearFrameBuffer (rmode, __xfb, COLOR_BLACK);

	/*** Set the framebuffer to be displayed at next VBlank ***/
	VIDEO_SetNextFramebuffer (__xfb);

	/*** Get the PAD status updated by libogc ***/
	//		VIDEO_SetPostRetraceCallback (updatePAD);
	VIDEO_SetBlack (0);

	/*** Update the video for next vblank ***/
	VIDEO_Flush ();

	VIDEO_WaitVSync ();		/*** Wait for VBL ***/
	if (rmode->viTVMode & VI_NON_INTERLACE)
		VIDEO_WaitVSync ();

	CON_Init(__xfb, 0, 0, rmode->fbWidth, rmode->xfbHeight, rmode->fbWidth * VI_DISPLAY_PIX_SZ);

	kprintf("\n\nKunaiLoader - based on iplboot\n");

	kunai_disable();

	// Set the timebase properly for games
	// Note: fuck libogc and dkppc
	u32 t = ticks_to_secs(SYS_Time());
	settime(secs_to_ticks(t));

	PAD_ScanPads();

	u16 all_buttons_held = (
			PAD_ButtonsHeld(PAD_CHAN0) |
			PAD_ButtonsHeld(PAD_CHAN1) |
			PAD_ButtonsHeld(PAD_CHAN2) |
			PAD_ButtonsHeld(PAD_CHAN3)
	);


	if (all_buttons_held & PAD_TRIGGER_Z) {
		draw_menu();
		while(all_buttons_held) {

			PAD_ScanPads();

			all_buttons_held = (
					PAD_ButtonsHeld(PAD_CHAN0) |
					PAD_ButtonsHeld(PAD_CHAN1) |
					PAD_ButtonsHeld(PAD_CHAN2) |
					PAD_ButtonsHeld(PAD_CHAN3)
			);
		};
		goto main_start;

	}

	for (int i = 0; i < num_shortcuts; i++) {
		if (all_buttons_held & shortcuts[i].pad_buttons) {
			path = shortcuts[i].path;
			break;
		}
	}

	CON_Init(__xfb, 0, 0, rmode->fbWidth, rmode->xfbHeight, rmode->fbWidth * VI_DISPLAY_PIX_SZ);

	kprintf("\n\nKunaiLoader - based on iplboot\n");

	if (all_buttons_held & PAD_BUTTON_START) {
		if (load_lfs("swiss.dol")) goto load;
	}

	if (load_usb('B')) goto load;

	if (load_fat("sdb", &__io_gcsdb)) goto load;

	if (load_usb('A')) goto load;

	if (load_fat("sda", &__io_gcsda)) goto load;

	if (load_fat("sd2", &__io_gcsd2)) goto load;

	load:
	// Wait to exit while the d-pad down direction is held.
	while (all_buttons_held & PAD_BUTTON_DOWN)
	{
		VIDEO_WaitVSync();
		PAD_ScanPads();
		all_buttons_held = (
				PAD_ButtonsHeld(PAD_CHAN0) |
				PAD_ButtonsHeld(PAD_CHAN1) |
				PAD_ButtonsHeld(PAD_CHAN2) |
				PAD_ButtonsHeld(PAD_CHAN3)
		);
	}

	if (dol)
	{
		memcpy((void *) STUB_ADDR, stub, stub_size);
		DCStoreRange((void *) STUB_ADDR, stub_size);

		SYS_ResetSystem(SYS_SHUTDOWN, 0, FALSE);
		SYS_SwitchFiber((intptr_t) dol, 0,
				(intptr_t) NULL, 0,
				STUB_ADDR, STUB_STACK);
	}
	// If we reach here, all attempts to load a DOL failed
	// Since we've disabled the Qoob, we wil reboot to the Nintendo IPL
	return 0;
}

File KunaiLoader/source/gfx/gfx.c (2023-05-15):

/*
This is the core graphics library for all our displays, providing a common
set of graphics primitives (points, lines, circles, etc.).  It needs to be
paired with a hardware-specific library for each display device we carry
(to handle the lower-level functions).

Adafruit invests time and resources providing this open source code, please
support Adafruit & open-source hardware by purchasing products from Adafruit!

Copyright (c) 2013 Adafruit Industries.  All rights reserved.

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
- Redistributions of source code must retain the above copyright notice,
  this list of conditions and the following disclaimer.
- Redistributions in binary form must reproduce the above copyright notice,
  this list of conditions and the following disclaimer in the documentation
  and/or other materials provided with the distribution.

THIS SOFTWARE IS PROVIDED BY THE COPYRIGHT HOLDERS AND CONTRIBUTORS "AS IS"
AND ANY EXPRESS OR IMPLIED WARRANTIES, INCLUDING, BUT NOT LIMITED TO, THE
IMPLIED WARRANTIES OF MERCHANTABILITY AND FITNESS FOR A PARTICULAR PURPOSE
ARE DISCLAIMED. IN NO EVENT SHALL THE COPYRIGHT HOLDER OR CONTRIBUTORS BE
LIABLE FOR ANY DIRECT, INDIRECT, INCIDENTAL, SPECIAL, EXEMPLARY, OR
CONSEQUENTIAL DAMAGES (INCLUDING, BUT NOT LIMITED TO, PROCUREMENT OF
SUBSTITUTE GOODS OR SERVICES; LOSS OF USE, DATA, OR PROFITS; OR BUSINESS
INTERRUPTION) HOWEVER CAUSED AND ON ANY THEORY OF LIABILITY, WHETHER IN
CONTRACT, STRICT LIABILITY, OR TORT (INCLUDING NEGLIGENCE OR OTHERWISE)
ARISING IN ANY WAY OUT OF THE USE OF THIS SOFTWARE, EVEN IF ADVISED OF THE
POSSIBILITY OF SUCH DAMAGE.
 */
#include "gfx.h"
#include "glcdfont.c"

// Many (but maybe not all) non-AVR board installs define macros
// for compatibility with existing PROGMEM-reading AVR code.
// Do our own checks and defines here for good measure...

#ifndef pgm_read_byte
#define pgm_read_byte(addr) (*(const unsigned char *)(addr))
#endif
#ifndef pgm_read_word
#define pgm_read_word(addr) (*(const unsigned short *)(addr))
#endif
#ifndef pgm_read_dword
#define pgm_read_dword(addr) (*(const unsigned long *)(addr))
#endif

// Pointers are a peculiar case...typically 16-bit on AVR boards,
// 32 bits elsewhere.  Try to accommodate both...

#if !defined(__INT_MAX__) || (__INT_MAX__ > 0xFFFF)
#define pgm_read_pointer(addr) ((void *)pgm_read_dword(addr))
#else
#define pgm_read_pointer(addr) ((void *)pgm_read_word(addr))
#endif

inline GFXglyph *pgm_read_glyph_ptr(const GFXfont *gfxFont, uint8_t c) {
#ifdef __AVR__
  return &(((GFXglyph *)pgm_read_pointer(&gfxFont->glyph))[c]);
#else
  // expression in __AVR__ section may generate "dereferencing type-punned
  // pointer will break strict-aliasing rules" warning In fact, on other
  // platforms (such as STM32) there is no need to do this pointer magic as
  // program memory may be read in a usual way So expression may be simplified
  return gfxFont->glyph + c;
#endif //__AVR__
}

inline uint8_t *pgm_read_bitmap_ptr(const GFXfont *gfxFont) {
#ifdef __AVR__
  return (uint8_t *)pgm_read_pointer(&gfxFont->bitmap);
#else
  // expression in __AVR__ section generates "dereferencing type-punned pointer
  // will break strict-aliasing rules" warning In fact, on other platforms (such
  // as STM32) there is no need to do this pointer magic as program memory may
  // be read in a usual way So expression may be simplified
  return gfxFont->bitmap;
#endif //__AVR__
}

#ifndef min
#define min(a, b) (((a) < (b)) ? (a) : (b))
#endif

#ifndef _swap_int16_t
#define _swap_int16_t(a, b)                                                    \
  {                                                                            \
    int16_t t = a;                                                             \
    a = b;                                                                     \
    b = t;                                                                     \
  }
#endif

/**
 * getcolour
 *
 * Simply converts RGB to Y1CbY2Cr format
 *
 * I got this from a pastebin, so thanks to whoever originally wrote it!
 */

unsigned int getColor(u8 r1, u8 g1, u8 b1)
{
	int y1, cb1, cr1, y2, cb2, cr2, cb, cr;
	u8 r2, g2, b2;

	r2 = r1;
	g2 = g1;
	b2 = b1;

	y1 = (299 * r1 + 587 * g1 + 114 * b1) / 1000;
	cb1 = (-16874 * r1 - 33126 * g1 + 50000 * b1 + 12800000) / 100000;
	cr1 = (50000 * r1 - 41869 * g1 - 8131 * b1 + 12800000) / 100000;

	y2 = (299 * r2 + 587 * g2 + 114 * b2) / 1000;
	cb2 = (-16874 * r2 - 33126 * g2 + 50000 * b2 + 12800000) / 100000;
	cr2 = (50000 * r2 - 41869 * g2 - 8131 * b2 + 12800000) / 100000;

	cb = (cb1 + cb2) >> 1;
	cr = (cr1 + cr2) >> 1;

	return ((y1 << 24) | (cb << 16) | (y2 << 8) | cr);
}

/****************************************************************************
* ClearScreen
****************************************************************************/
void ClearScreen (){
  VIDEO_ClearFrameBuffer (rmode, __xfb, COL_BLACK);
}

/****************************************************************************
* ShowScreen
****************************************************************************/
void ShowScreen ()
{
	VIDEO_SetNextFramebuffer (__xfb);
	VIDEO_Flush ();
	VIDEO_WaitVSync ();
}

/**************************************************************************/
/*!
   @brief    Write a line.  Bresenham's algorithm - thx wikpedia
    @param    x0  Start point x coordinate
    @param    y0  Start point y coordinate
    @param    x1  End point x coordinate
    @param    y1  End point y coordinate
    @param    color 16-bit 5-6-5 Color to draw with
*/
/**************************************************************************/
void writeLine(int16_t x0, int16_t y0, int16_t x1, int16_t y1, int color) {

  int16_t steep = abs(y1 - y0) > abs(x1 - x0);
  if (steep) {
    _swap_int16_t(x0, y0);
    _swap_int16_t(x1, y1);
  }

  if (x0 > x1) {
    _swap_int16_t(x0, x1);
    _swap_int16_t(y0, y1);
  }

  int16_t dx, dy;
  dx = x1 - x0;
  dy = abs(y1 - y0);

  int16_t err = dx / 2;
  int16_t ystep;

  if (y0 < y1) {
    ystep = 1;
  } else {
    ystep = -1;
  }

  for (; x0 <= x1; x0++) {
    if (steep) {
      writePixel(y0, x0, color);
    } else {
      writePixel(x0, y0, color);
    }
    err -= dy;
    if (err < 0) {
      y0 += ystep;
      err += dx;
    }
  }
}

/**************************************************************************/
/*!
   @brief    Write a pixel, overwrite in subclasses if startWrite is defined!
    @param   x   x coordinate
    @param   y   y coordinate
   @param    color 32-bit Y1CbY2Cr
*/
/**************************************************************************/
void writePixel(int16_t x, int16_t y, u32 color) {
	u32 *tmpfb = (u32 *) __xfb;
	u32 offset = (x/2) + ((rmode->fbWidth/2) * y);
	u32 pixel_new = (tmpfb[offset] & (x%2 ? 0xFFFF0000 : 0xFFFF)) | ( color   << (x%2 ? 0 : 16UL));
	tmpfb[offset] = pixel_new;
}
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

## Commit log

2023-05-15 Merge (#3)
    * initial commit
    * added PCB-Files
    * updated sources + makefiles
    * added QSB for DOL-101
    * Implemented LFS into KunaiRecovery
    * updated to latest files
    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
    [KunaiGC_QSB.kicad_pcb, KunaiGC_QSB.kicad_sch, KunaiGC_QSB_101.kicad_pcb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]
2023-10-04 Fix: Increase Offset during Multi Block Write (#14)
    * Fix: Increase offset during multi block write
    * Add Debug Capabilities for SPI
    ---------
    [kunaigc.c, spiflash.c]
